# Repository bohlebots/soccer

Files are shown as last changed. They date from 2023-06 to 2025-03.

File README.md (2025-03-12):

# Bohlebots
<h2>collection of all published and open source software and hardware from the Bohlebots.</h2>
We are a team of students at the Gymnasium Haan in Germany. We call ourselves Bohlebots
due to the support of the Bohle company at our home town Haan.

We decided to put all our robotic stuff opensource. This includes arduino files and libraries,
eagle pcb files () and eagle libraries (lbr) for all our baords.
This page is under construction and it suffers from the inactivity of the author.
BUT:

We are also taking part at the development of the https://github.com/CoRoSoN-Kit/CoRoSoN-Kit.
The aktual bohlbots CoRoSoN Kit is lokated under https://github.com/ItzJannis/CoRoSoN-Package_Draft

Here is a photo of the prototypes of a mainboard and an IR-seeker-ring:
grafik

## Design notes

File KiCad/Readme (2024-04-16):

These are the current KiCad project files of the season 2024.
These boards are used by the bohlebots 1vs1 teams and can be used as CoRoSoN Kit boards as well

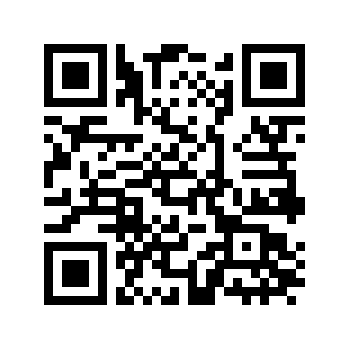
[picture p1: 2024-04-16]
KiCad/github.png

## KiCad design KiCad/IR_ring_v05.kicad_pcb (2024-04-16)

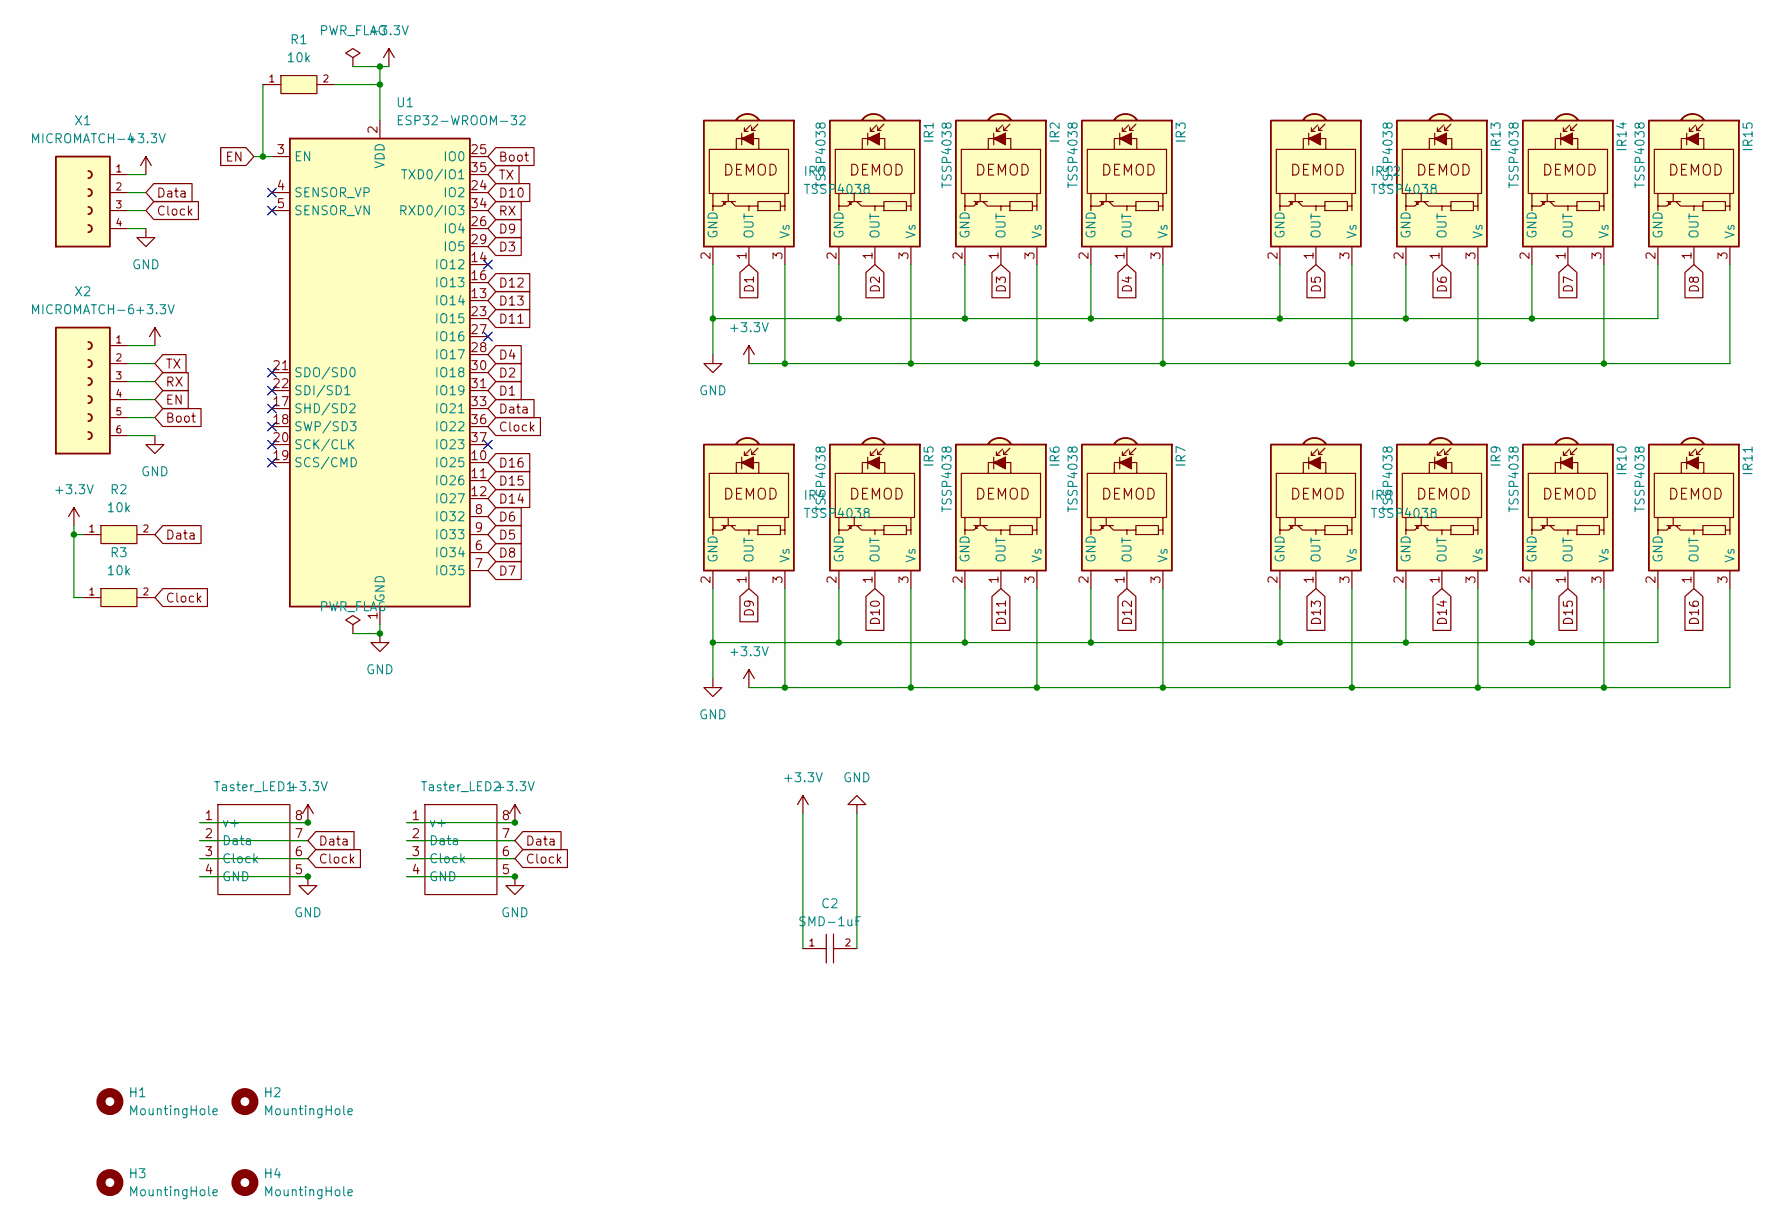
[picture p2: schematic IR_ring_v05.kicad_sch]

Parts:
C2: SMD-1uF; C0603; LCSC C1592
H1, H2, H3, H4: MountingHole; MountingHole_4.3mm_M4
IR0, IR1, IR2, IR3, IR4, IR5, IR6, IR7, IR8, IR9, IR10, IR11, IR12, IR13, IR14, IR15: TSSP4038; SENSOR-TH_TSSP40X_verschoben; LCSC Part # C143753
R1, R2, R3: 10k; R0603; LCSC C465463
Taster_LED1, Taster_LED2: TASTER_LED
U1: ESP32-WROOM-32; ESP32-WROOM-32-small; LCSC Part # C82899
X1: MICROMATCH-4
X2: MICROMATCH-6

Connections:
+3.3V: C2.1, IR0.3 (Vs), IR1.3 (Vs), IR2.3 (Vs), IR3.3 (Vs), IR4.3 (Vs), IR5.3 (Vs), IR6.3 (Vs), IR7.3 (Vs), IR8.3 (Vs), IR9.3 (Vs), IR10.3 (Vs), IR11.3 (Vs), IR12.3 (Vs), IR13.3 (Vs), IR14.3 (Vs), IR15.3 (Vs), R1.2, R2.1, R3.1, Taster_LED1.1 (v+), Taster_LED1.8, Taster_LED2.1 (v+), Taster_LED2.8, U1.2 (VDD), X1.1, X2.1
Boot: U1.25 (IO0), X2.5
Clock: R3.2, Taster_LED1.3 (Clock), Taster_LED1.6, Taster_LED2.3 (Clock), Taster_LED2.6, U1.36 (IO22), X1.3
D1: IR0.1 (OUT), U1.31 (IO19)
D2: IR1.1 (OUT), U1.30 (IO18)
D3: IR2.1 (OUT), U1.29 (IO5)
D4: IR3.1 (OUT), U1.28 (IO17)
D5: IR12.1 (OUT), U1.9 (IO33)
D6: IR13.1 (OUT), U1.8 (IO32)
D7: IR14.1 (OUT), U1.7 (IO35)
D8: IR15.1 (OUT), U1.6 (IO34)
D9: IR4.1 (OUT), U1.26 (IO4)
D10: IR5.1 (OUT), U1.24 (IO2)
D11: IR6.1 (OUT), U1.23 (IO15)
D12: IR7.1 (OUT), U1.16 (IO13)
D13: IR8.1 (OUT), U1.13 (IO14)
D14: IR9.1 (OUT), U1.12 (IO27)
D15: IR10.1 (OUT), U1.11 (IO26)
D16: IR11.1 (OUT), U1.10 (IO25)
Data: R2.2, Taster_LED1.2 (Data), Taster_LED1.7, Taster_LED2.2 (Data), Taster_LED2.7, U1.33 (IO21), X1.2
EN: R1.1, U1.3 (EN), X2.4
GND: C2.2, IR0.2 (GND), IR1.2 (GND), IR2.2 (GND), IR3.2 (GND), IR4.2 (GND), IR5.2 (GND), IR6.2 (GND), IR7.2 (GND), IR8.2 (GND), IR9.2 (GND), IR10.2 (GND), IR11.2 (GND), IR12.2 (GND), IR13.2 (GND), IR14.2 (GND), IR15.2 (GND), Taster_LED1.4 (GND), Taster_LED1.5, Taster_LED2.4 (GND), Taster_LED2.5, U1.1 (GND), U1.15 (GND), U1.38 (GND), U1.39 (GND), X1.4, X2.6
RX: U1.34 (RXD0/IO3), X2.3
TX: U1.35 (TXD0/IO1), X2.2

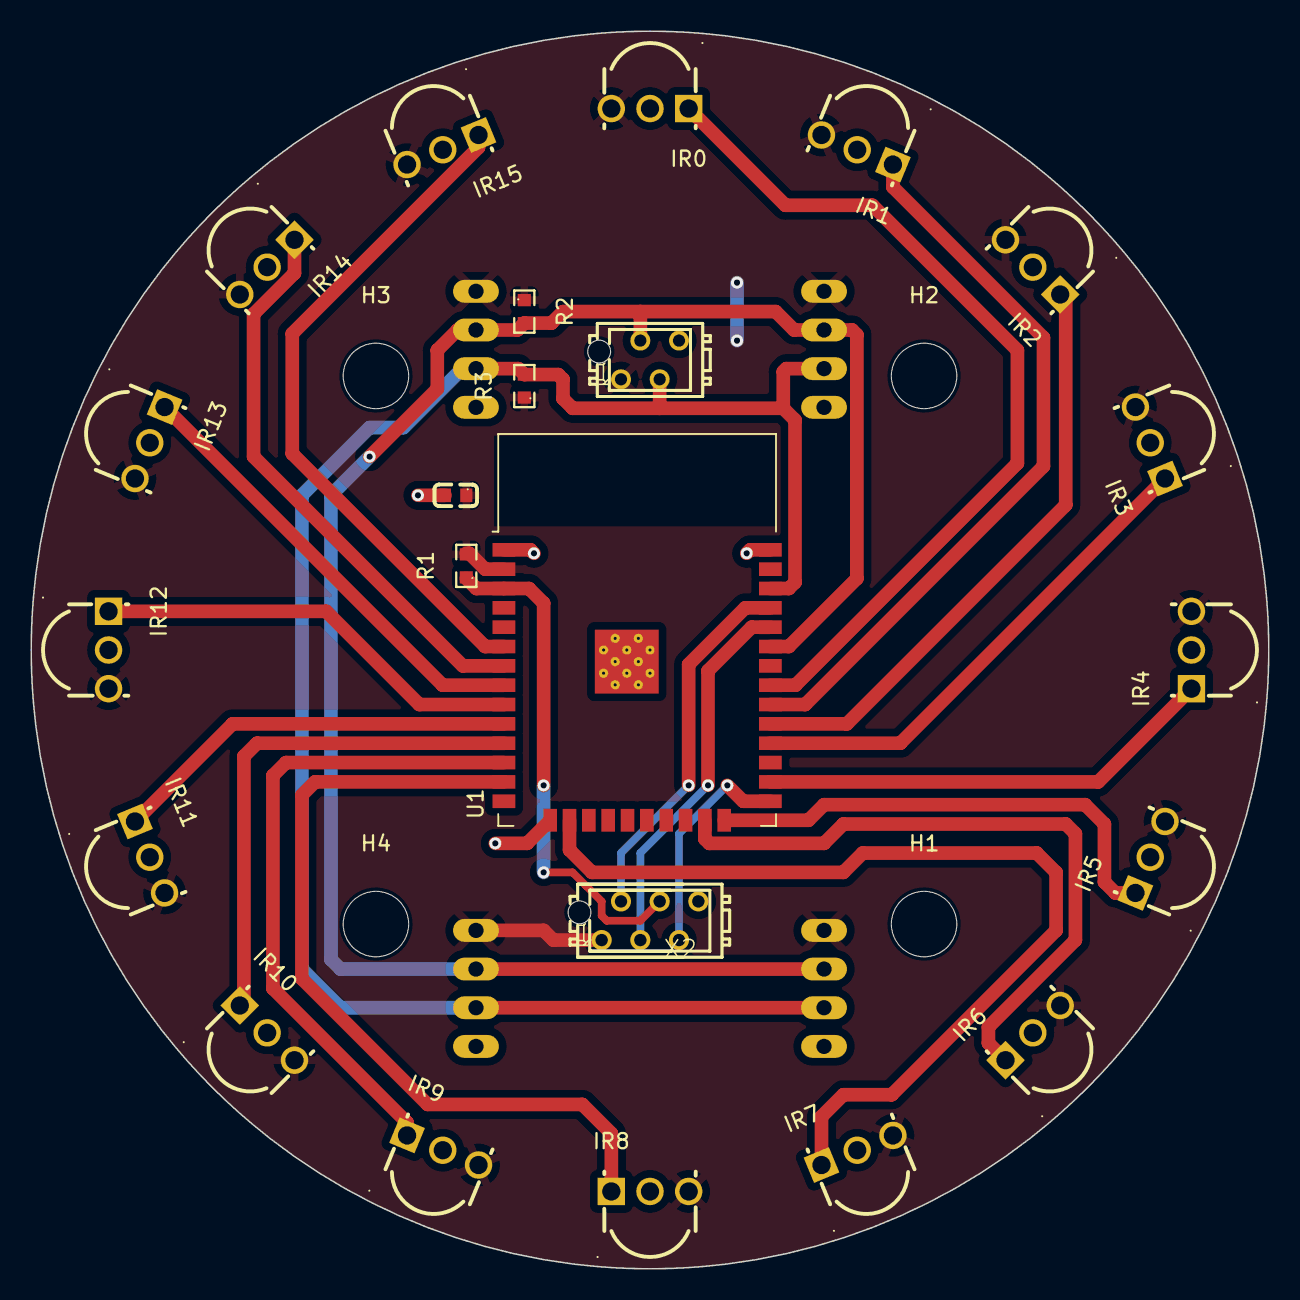
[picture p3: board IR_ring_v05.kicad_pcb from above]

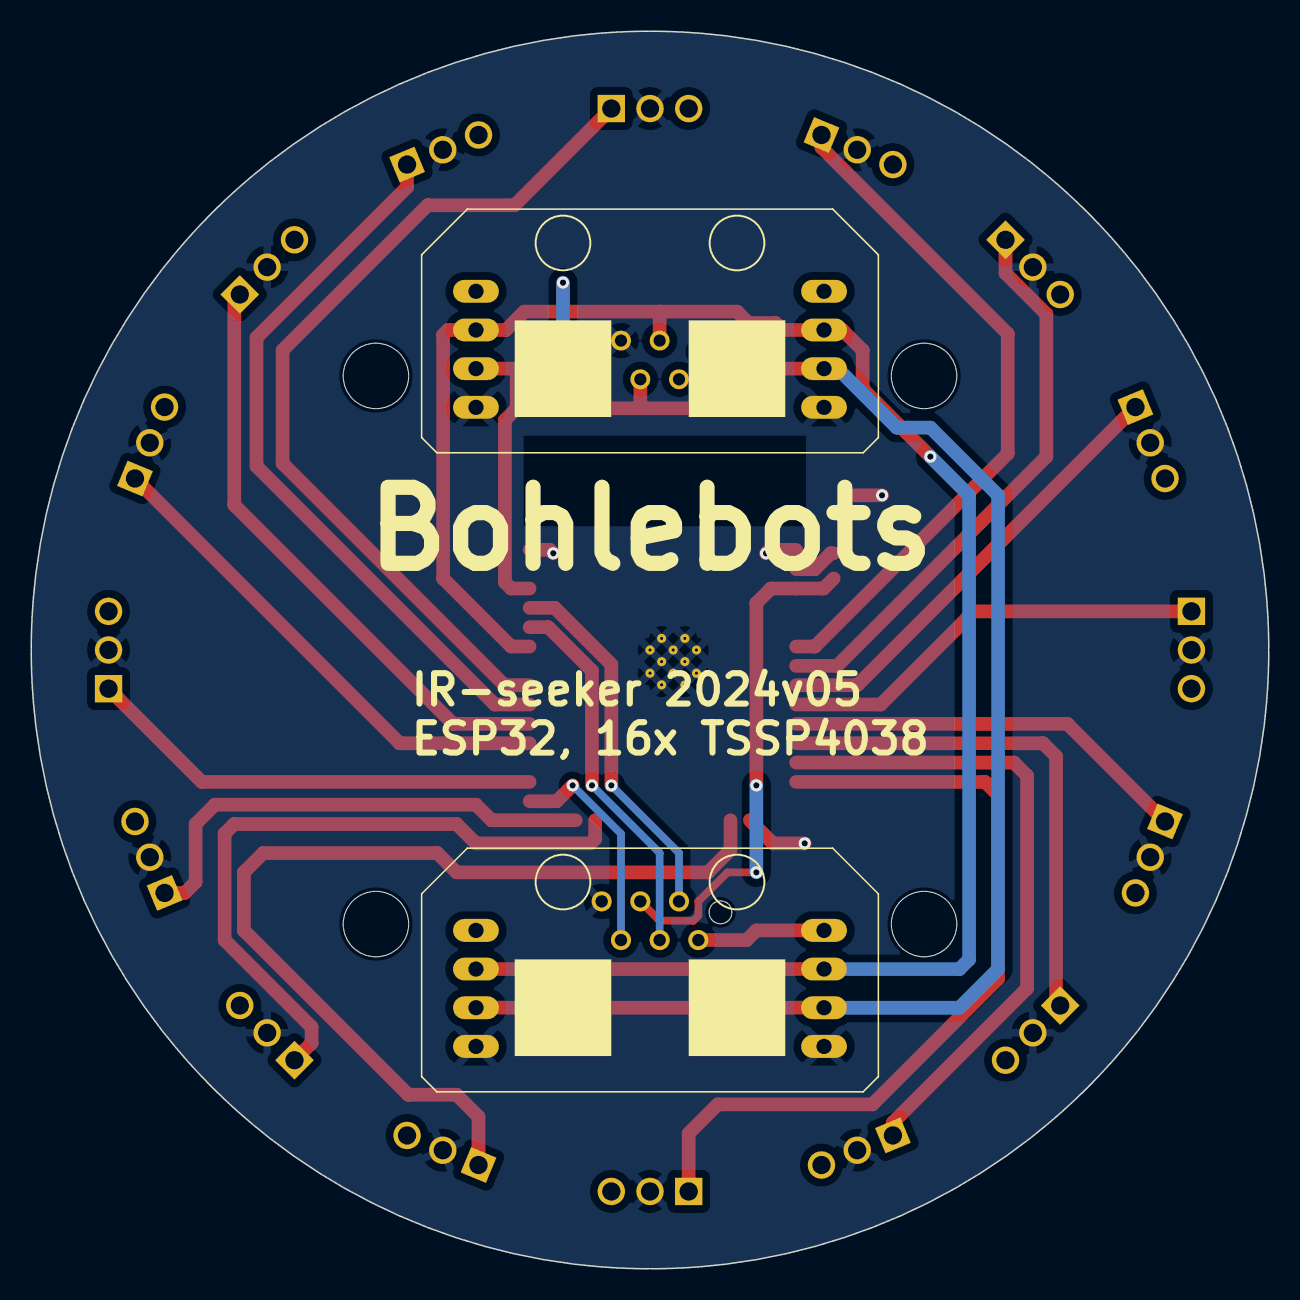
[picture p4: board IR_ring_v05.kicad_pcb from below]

Board: 2 copper layers, 81.3 x 81.3 mm, 29 parts (2 on the bottom side), 24 nets.

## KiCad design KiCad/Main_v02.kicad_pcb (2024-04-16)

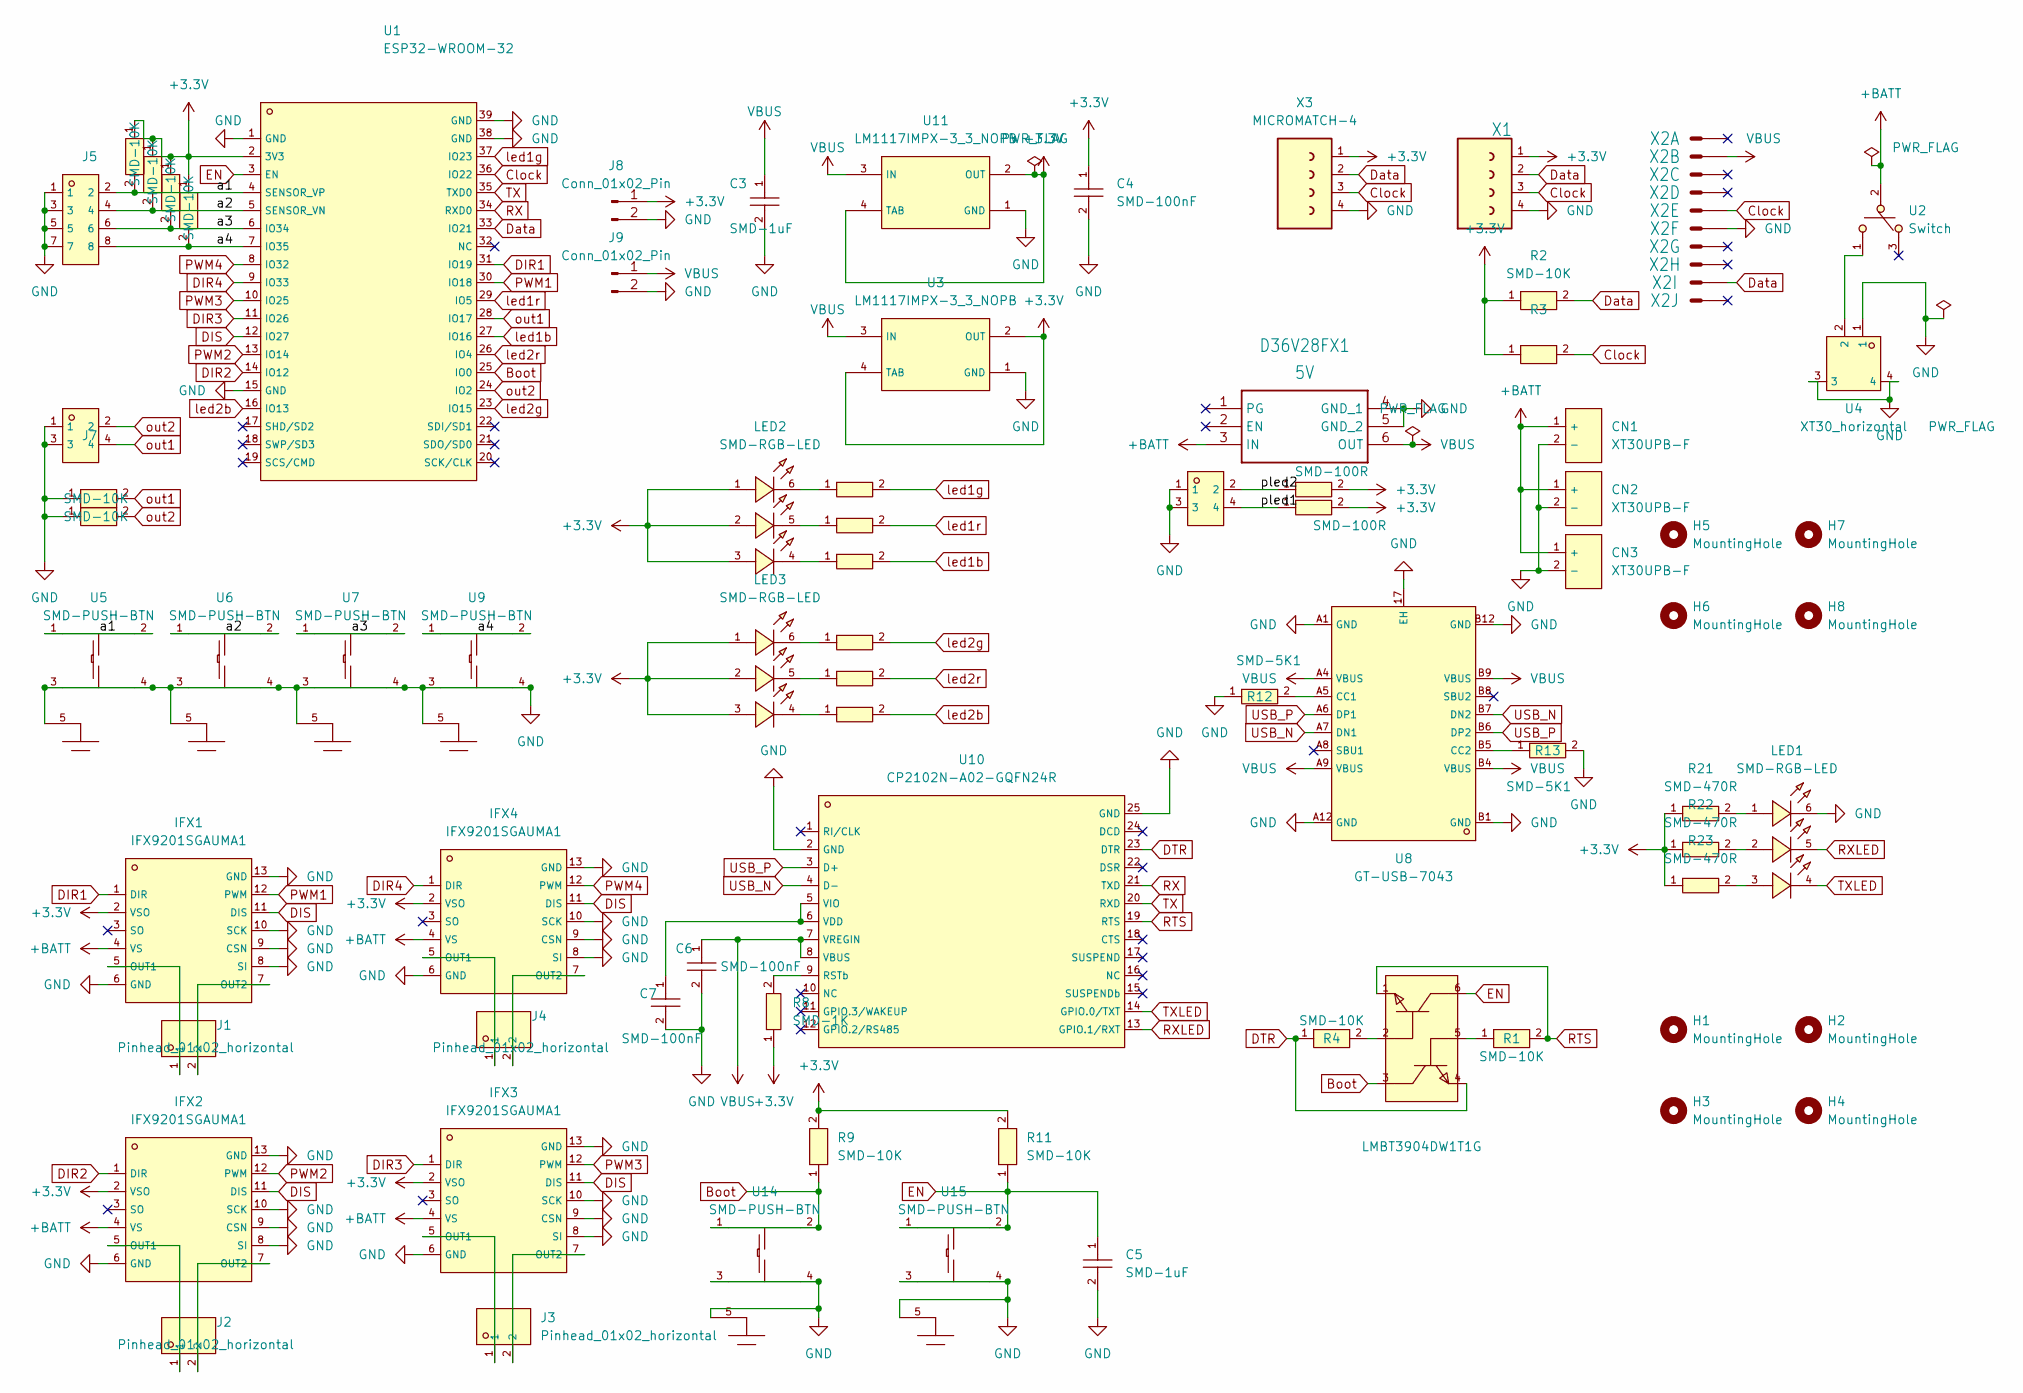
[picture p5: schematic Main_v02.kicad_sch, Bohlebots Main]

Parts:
C3, C5: SMD-1uF; C0603; LCSC C1592
C4, C6, C7: SMD-100nF; C0603; LCSC C30926
CN1, CN2, CN3: XT30UPB-F; CONN-TH_XT30UPB-F; LCSC C108769
D36V28FX1: 5V; D36V28FX
H1, H2, H3, H4, H5, H6, H7, H8: MountingHole; MountingHole_4.3mm_M4
IFX1, IFX2, IFX3, IFX4: IFX9201SGAUMA1; SO-12_L6.4-W7.5-P1.00-LS10.3-BL-EP; LCSC C112633
J1, J2, J3, J4: Pinhead_01x02_horizontal; HDR-TH_2P-P2.54-H-M-W10.4; LCSC C492410
J5: Conn_02x04_Row_Letter_First; HDR-TH_8P-P2.54-H-M-R2-C4-S2.54; LCSC C706885
J6, J7: Conn_02x02_Row_Letter_First; HDR-TH_4P-P2.54-H-M-R2-C2-S2.54-W12.3-N; LCSC C706883
J8, J9: Conn_01x02_Pin; PinHeader_1x02_P2.54mm_Vertical
LED1, LED2, LED3: SMD-RGB-LED; LED-SMD_6P-L5.0-W5.0-TL_TC5050RGBF08; LCSC C784540
R1, R2, R3, R4, R5, R6, R7, R9, R10, R11, R14, R15: SMD-10K; R0603; LCSC C465463
R8: SMD-1K; R0603; LCSC C22548
R12, R13: SMD-5K1; R0603; LCSC C103696
R16, R17, R20, R21, R22, R23, R24, R25, R26: SMD-470R; R0603; LCSC C23162
R18, R19: SMD-100R; R0603; LCSC C22775
U1: ESP32-WROOM-32; WIFIM-SMD_ESP32-WROOM-32-N4; LCSC C82899
U2: Switch; SW-TH_MT-0-103-A101-M200-RS; LCSC C1788498
U3, U11: LM1117IMPX-3_3_NOPB; SOT-223_L6.5-W3.5-P2.30-LS7.0-BR; LCSC C23984
U4: XT30_horizontal; CONN-TH_XT30PW-M; LCSC C431092
U5, U6, U7, U9, U14, U15: SMD-PUSH-BTN; SW-TH_5P-L6.0-W6.0-P4.50-LS6.5; LCSC C470256
U8: GT-USB-7043; USB-C-SMD_GT-USB-7043; LCSC C2762982
U10: CP2102N-A02-GQFN24R; QFN-24_L4.0-W4.0-P0.50-TL-EP2.6; LCSC C969151
U12: LMBT3904DW1T1G; SOT-363_L2.0-W1.3-P0.65-LS2.1-BR; LCSC C131781
X1: MICROMATCH-4
X2: MICROMATCH-10
X3: MICROMATCH-4

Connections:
+3.3V: C4.1, IFX1.2 (VSO), IFX2.2 (VSO), IFX3.2 (VSO), IFX4.2 (VSO), J8.1, LED2.1 (+), LED2.2 (+), LED2.3 (+), LED3.1 (+), LED3.2 (+), LED3.3 (+), R2.1, R3.1, R5.1, R6.1, R7.1, R8.1, R9.2, R10.1, R11.2, R18.2, R19.2, R21.1, R22.1, R23.1, U1.2 (3V3), U3.2 (OUT), U3.4 (TAB), U11.2 (OUT), U11.4 (TAB), X1.1, X3.1
+BATT: CN1.1 (+), CN2.1 (+), CN3.1 (+), D36V28FX1.3 (IN), IFX1.4 (VS), IFX2.4 (VS), IFX3.4 (VS), IFX4.4 (VS), U2.2
/a1: J5.2, R5.2, U1.4 (SENSOR_VP), U5.1, U5.2
/a2: J5.4, R6.2, U1.5 (SENSOR_VN), U6.1, U6.2
/a3: J5.6, R7.2, U1.6 (IO34), U7.1, U7.2
/a4: J5.8, R10.2, U1.7 (IO35), U9.1, U9.2
/pled1: J6.4, R19.1
/pled2: J6.2, R18.1
Boot: R9.1, U1.25 (IO0), U12.3 (C), U14.1, U14.2
Clock: R3.2, U1.36 (IO22), X1.3, X2.5 (S), X3.3
DIR1: IFX1.1 (DIR), U1.31 (IO19)
DIR2: IFX2.1 (DIR), U1.14 (IO12)
DIR3: IFX3.1 (DIR), U1.11 (IO26)
DIR4: IFX4.1 (DIR), U1.9 (IO33)
DIS: IFX1.11 (DIS), IFX2.11 (DIS), IFX3.11 (DIS), IFX4.11 (DIS), U1.12 (IO27)
DTR: R4.1, U10.23 (DTR), U12.4 (E)
Data: R2.2, U1.33 (IO21), X1.2, X2.9 (S), X3.2
EN: C5.1, R11.1, U1.3 (EN), U12.6 (C), U15.1, U15.2
GND: C3.2, C4.2, C5.2, C6.2, C7.2, CN1.2 (-), CN2.2 (-), CN3.2 (-), D36V28FX1.4 (GND_1), D36V28FX1.5 (GND_2), IFX1.6 (GND), IFX1.8 (SI), IFX1.9 (CSN), IFX1.10 (SCK), IFX1.13 (GND), IFX2.6 (GND), IFX2.8 (SI), IFX2.9 (CSN), IFX2.10 (SCK), IFX2.13 (GND), IFX3.6 (GND), IFX3.8 (SI), IFX3.9 (CSN), IFX3.10 (SCK), IFX3.13 (GND), IFX4.6 (GND), IFX4.8 (SI), IFX4.9 (CSN), IFX4.10 (SCK), IFX4.13 (GND), J5.1, J5.3, J5.5, J5.7, J6.1, J6.3, J7.1, J7.3, J8.2, J9.2, LED1.6 (-), R12.1, R13.2, R14.1, R15.1, U1.1 (GND), U1.15 (GND), U1.38 (GND), U1.39 (GND), U3.1 (GND), U4.1, U4.3, U4.4, U5.3, U5.4, U5.5, U6.3, U6.4, U6.5, U7.3, U7.4, U7.5, U8.17 (EH), U8.A1 (GND), U8.A12 (GND), U8.B1 (GND), U8.B12 (GND), U9.3, U9.4, U9.5, U10.2 (GND), U10.25 (GND), U11.1 (GND), U14.3, U14.4, U14.5, U15.3, U15.4, U15.5, X1.4, X2.6 (S), X3.4
unnamed: IFX1.5 (OUT1), J1.1
unnamed: IFX1.7 (OUT2), J1.2
unnamed: IFX2.5 (OUT1), J2.1
unnamed: IFX2.7 (OUT2), J2.2
unnamed: IFX3.5 (OUT1), J3.1
unnamed: IFX3.7 (OUT2), J3.2
unnamed: IFX4.5 (OUT1), J4.1
unnamed: IFX4.7 (OUT2), J4.2
unnamed: LED1.1 (+), R21.2
unnamed: LED1.2 (+), R22.2
unnamed: LED1.3 (+), R23.2
unnamed: LED2.4 (-), R20.1
unnamed: LED2.5 (-), R17.1
unnamed: LED2.6 (-), R16.1
unnamed: LED3.4 (-), R26.1
unnamed: LED3.5 (-), R25.1
unnamed: LED3.6 (-), R24.1
unnamed: R1.1, U12.5 (B)
unnamed: R4.2, U12.2 (B)
unnamed: U2.1, U4.2
unnamed: R12.2, U8.A5 (CC1)
unnamed: R13.1, U8.B5 (CC2)
unnamed: R8.2, U10.9 (RSTb)
unnamed: C7.1, U10.5 (VIO), U10.6 (VDD)
PWM1: IFX1.12 (PWM), U1.30 (IO18)
PWM2: IFX2.12 (PWM), U1.13 (IO14)
PWM3: IFX3.12 (PWM), U1.10 (IO25)
PWM4: IFX4.12 (PWM), U1.8 (IO32)
RTS: R1.2, U10.19 (RTS), U12.1 (E)
RX: U1.34 (RXD0), U10.21 (TXD)
RXLED: LED1.5 (-), U10.13 (GPIO.1/RXT)
TX: U1.35 (TXD0), U10.20 (RXD)
TXLED: LED1.4 (-), U10.14 (GPIO.0/TXT)
USB_N: U8.A7 (DN1), U8.B7 (DN2), U10.4 (D-)
USB_P: U8.A6 (DP1), U8.B6 (DP2), U10.3 (D+)
VBUS: C3.1, C6.1, D36V28FX1.6 (OUT), J9.1, U3.3 (IN), U8.A4 (VBUS), U8.A9 (VBUS), U8.B4 (VBUS), U8.B9 (VBUS), U10.7 (VREGIN), U10.8 (VBUS), U11.3 (IN), X2.2 (S)
led1b: R20.2, U1.27 (IO16)
led1g: R16.2, U1.37 (IO23)
led1r: R17.2, U1.29 (IO5)
led2b: R26.2, U1.16 (IO13)
led2g: R24.2, U1.23 (IO15)
led2r: R25.2, U1.26 (IO4)
out1: J7.4, R14.2, U1.28 (IO17)
out2: J7.2, R15.2, U1.24 (IO2)

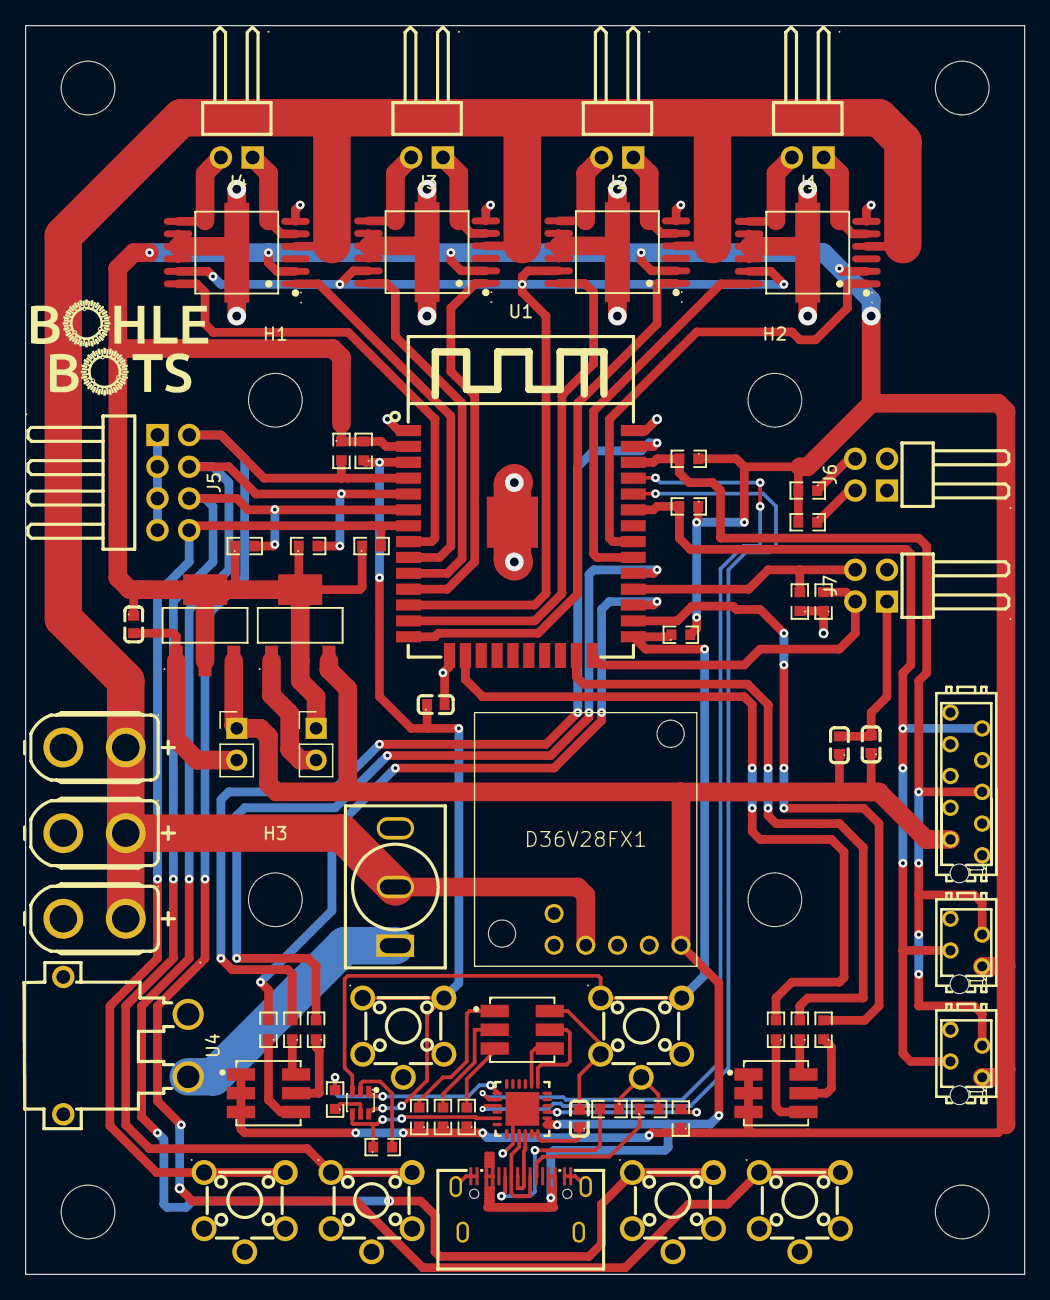
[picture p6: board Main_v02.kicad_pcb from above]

Board: 2 copper layers, 80.0 x 100.0 mm, 76 parts (0 on the bottom side), 63 nets.

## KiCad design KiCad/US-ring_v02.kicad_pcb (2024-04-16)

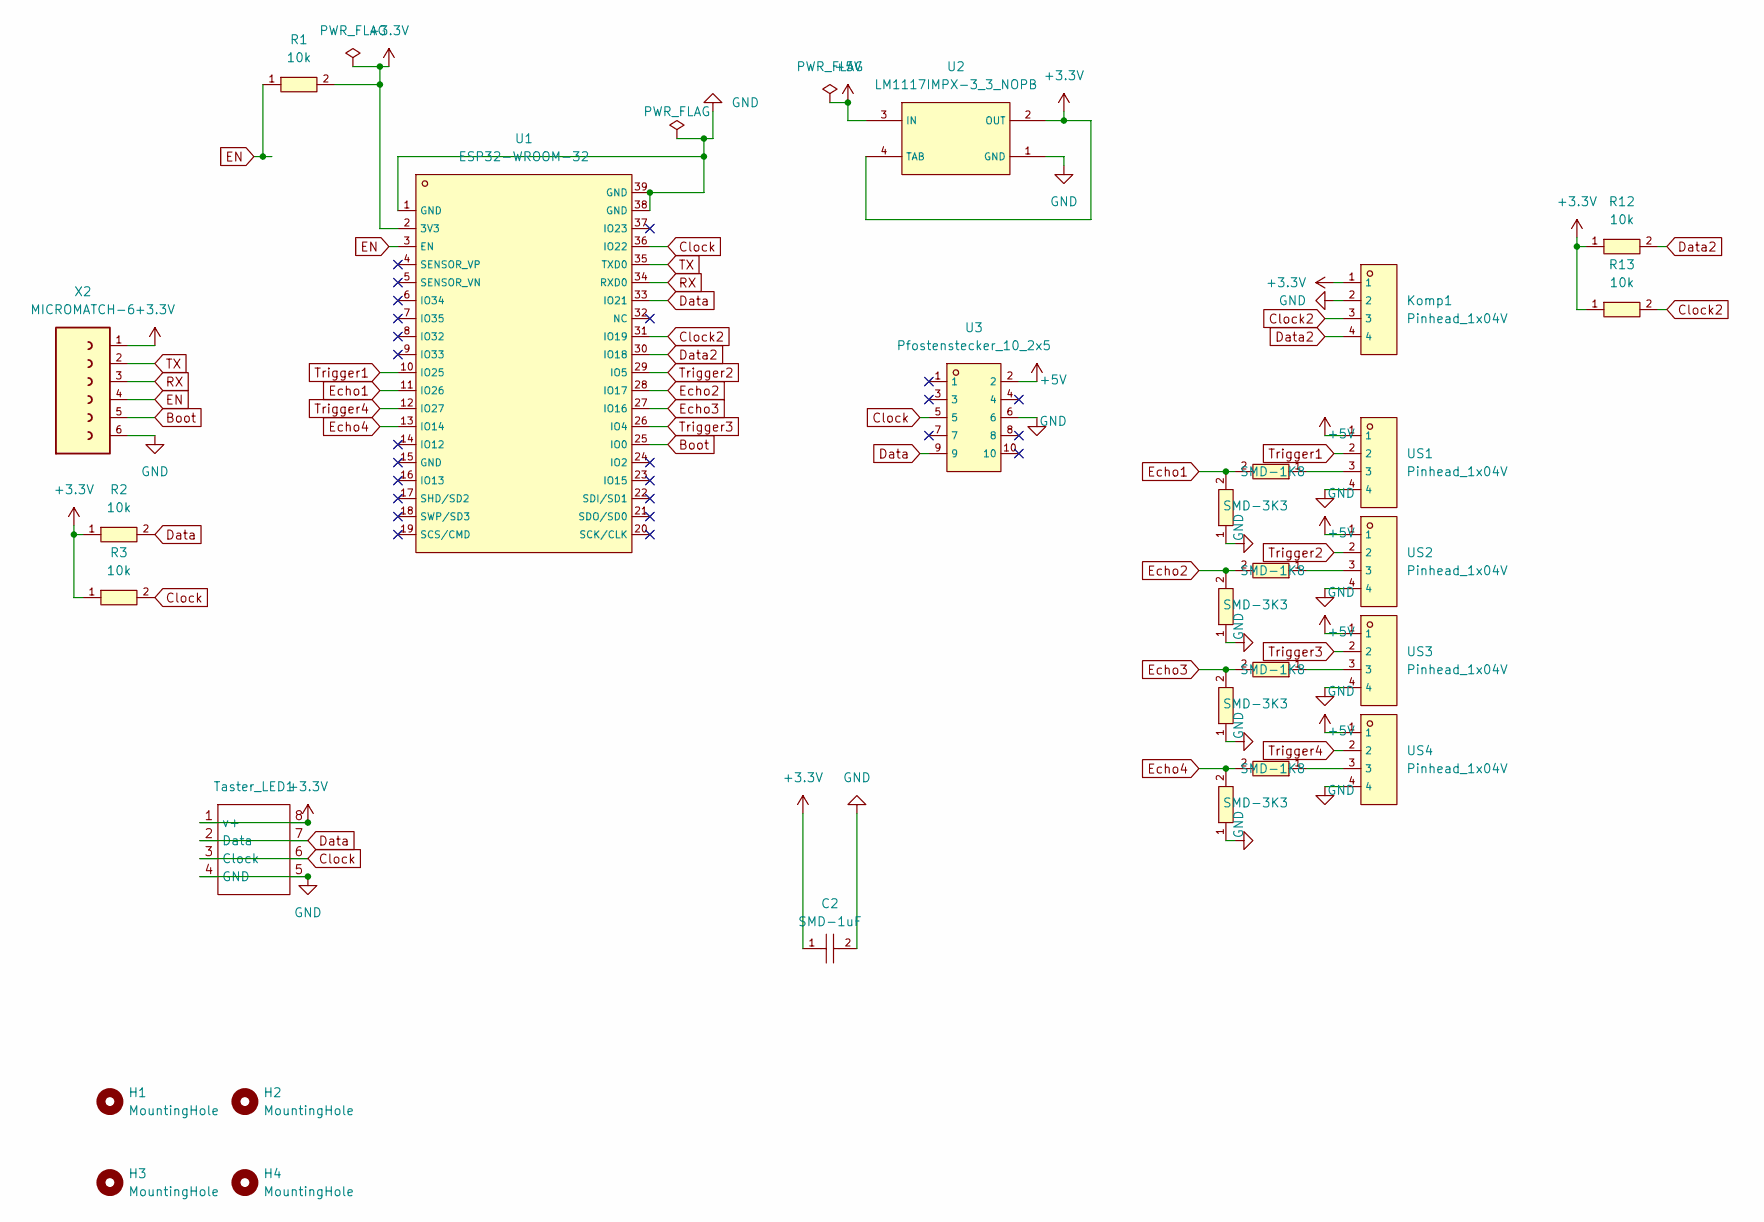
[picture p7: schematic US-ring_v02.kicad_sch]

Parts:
C2: SMD-1uF; C0603; LCSC C1592
H1, H2, H3, H4: MountingHole; MountingHole_4.3mm_M4
Komp1: Pinhead_1x04V; HDR-TH_4P-P2.54-V-M-1; LCSC C920779
R1, R2, R3, R12, R13: 10k; R0603; LCSC C25804
R4, R7, R8, R10: SMD-3K3; R0603; LCSC C22978
R5, R6, R9, R11: SMD-1K8; R0603; LCSC C4177
Taster_LED1: TASTER_LED
U1: ESP32-WROOM-32; WIFIM-SMD_ESP32-WROOM-32-N4; LCSC Part # C82899
U2: LM1117IMPX-3_3_NOPB; SOT-223_L6.5-W3.5-P2.30-LS7.0-BR; LCSC C23984
U3: Pfostenstecker_10_2x5; HDR-TH_10P-P2.54-V-F-R2-C5-S2.54-5; LCSC C5372865
US1, US2, US3, US4: Pinhead_1x04V; HDR-TH_4P-P2.54-V-M-1; LCSC C920779
X2: MICROMATCH-6

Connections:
+3.3V: C2.1, Komp1.1, R1.2, R2.1, R3.1, R12.1, R13.1, Taster_LED1.1 (v+), Taster_LED1.8, U1.2 (3V3), U2.2 (OUT), U2.4 (TAB), X2.1
+5V: U2.3 (IN), U3.2, US1.1, US2.1, US3.1, US4.1
Boot: U1.25 (IO0), X2.5
Clock: R3.2, Taster_LED1.3 (Clock), Taster_LED1.6, U1.36 (IO22), U3.5
Clock2: Komp1.3, R13.2, U1.31 (IO19)
Data: R2.2, Taster_LED1.2 (Data), Taster_LED1.7, U1.33 (IO21), U3.9
Data2: Komp1.4, R12.2, U1.30 (IO18)
EN: R1.1, U1.3 (EN), X2.4
Echo1: R10.2, R11.2, U1.11 (IO26)
Echo2: R6.2, R7.2, U1.28 (IO17)
Echo3: R4.2, R5.2, U1.27 (IO16)
Echo4: R8.2, R9.2, U1.13 (IO14)
GND: C2.2, Komp1.2, R4.1, R7.1, R8.1, R10.1, Taster_LED1.4 (GND), Taster_LED1.5, U1.1 (GND), U1.38 (GND), U1.39 (GND), U2.1 (GND), U3.6, US1.4, US2.4, US3.4, US4.4, X2.6
unnamed: R5.1, US3.3
unnamed: R6.1, US2.3
unnamed: R9.1, US4.3
unnamed: R11.1, US1.3
RX: U1.34 (RXD0), X2.3
TX: U1.35 (TXD0), X2.2
Trigger1: U1.10 (IO25), US1.2
Trigger2: U1.29 (IO5), US2.2
Trigger3: U1.26 (IO4), US3.2
Trigger4: U1.12 (IO27), US4.2

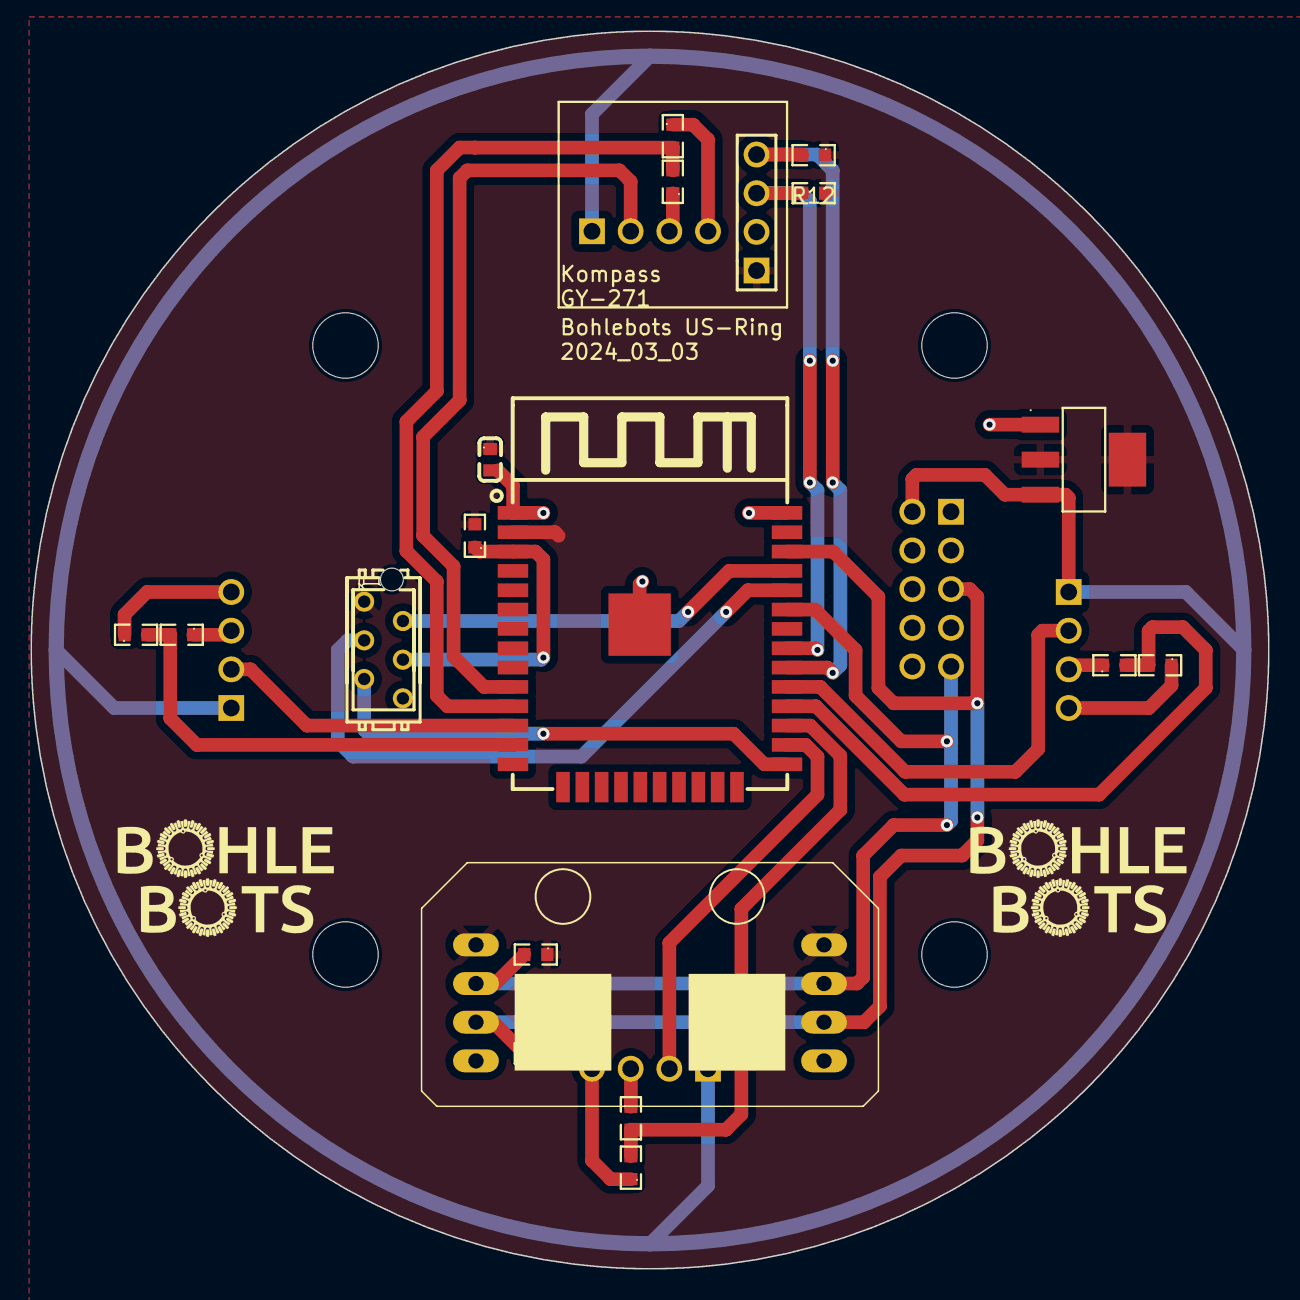
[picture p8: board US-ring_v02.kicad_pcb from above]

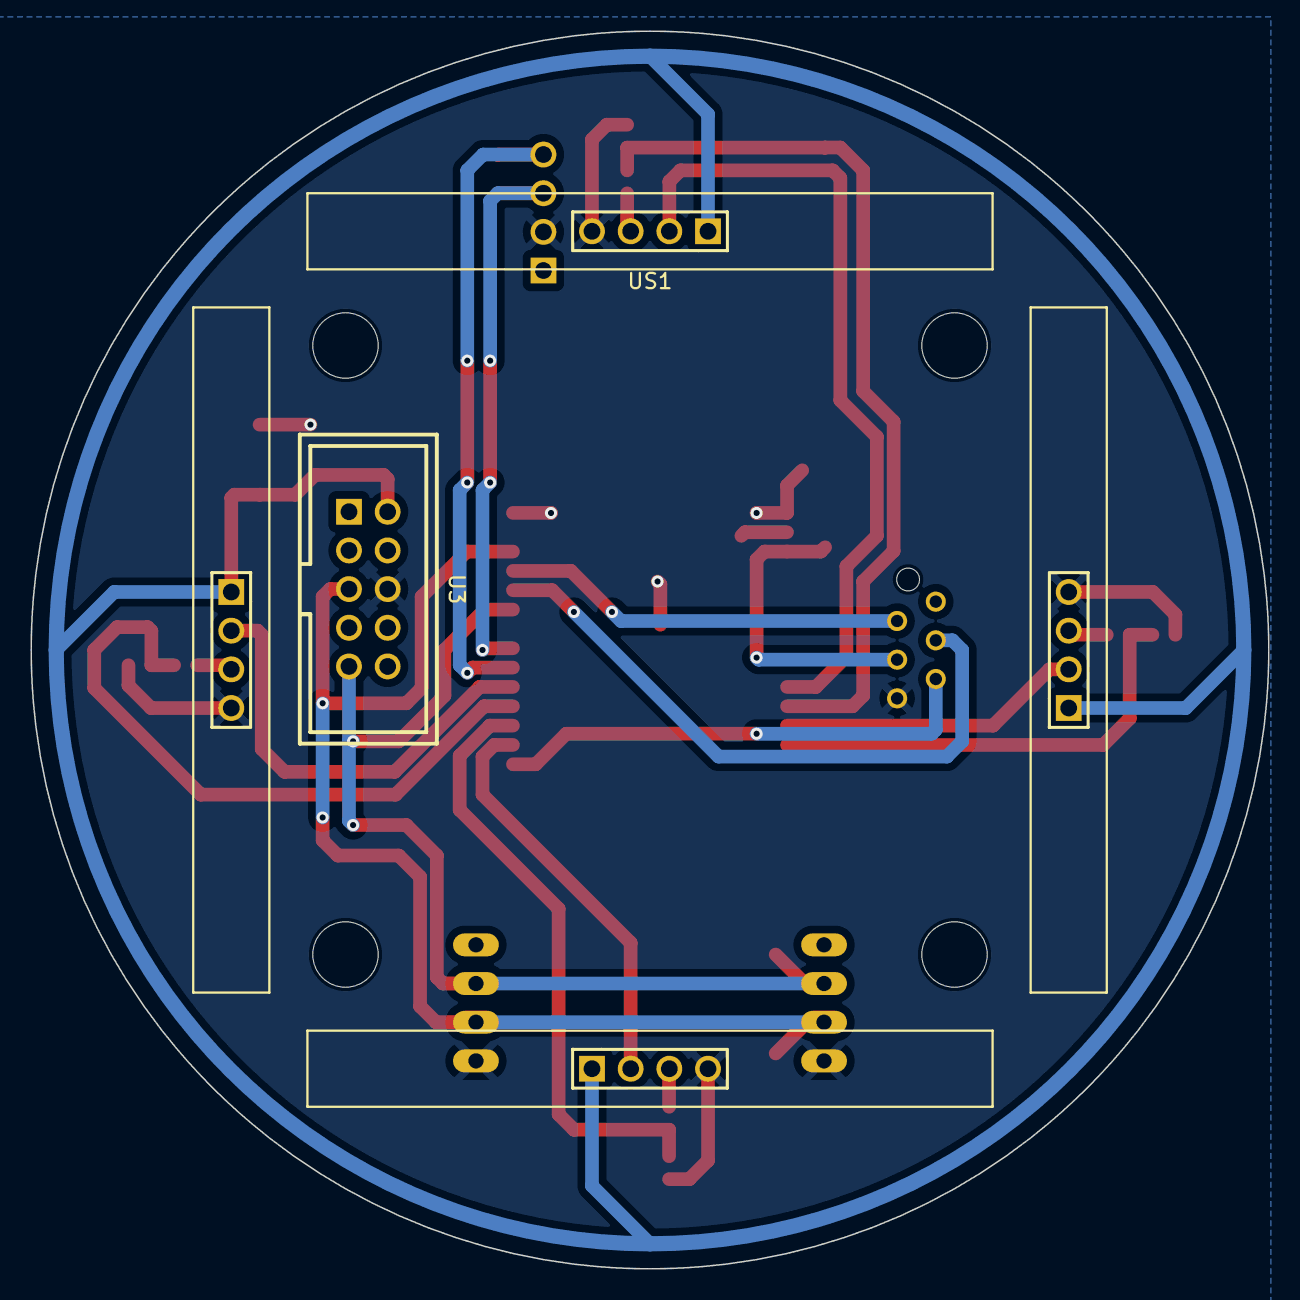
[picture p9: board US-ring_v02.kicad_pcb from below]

Board: 2 copper layers, 81.3 x 81.3 mm, 28 parts (5 on the bottom side), 23 nets.

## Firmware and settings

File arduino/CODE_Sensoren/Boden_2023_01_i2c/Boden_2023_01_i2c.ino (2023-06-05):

/*
   Bodensensor Canbus Platine 2022_01_10
		Serielle ausgabe in Line 215
*/

#include <elapsedMillis.h>
#include <Wire.h>
#define I2C_DEV_ADDR 0x30
#define TOT 2 // hier wird die Totzeit gesetzt. Je ein TOT entspricht 20ms. eine TOT von 5 ist 100ms

#include "Zuordnung.h"
elapsedMillis zeit;

int schwellwert = 250;  // setzen und immer wieder prüfen !!!


int sensor[] = { 26, 33, 32, 25}; // 4 Ananlogeingänge für 4 Multiplexer
int zonen[] = { 0, 0, 0, 0, 0, 0, 0, 0, 0};
byte zuordnungzone = 0b00000000;

int bodenled = 2;

int add0 = 13; // 8 port Multiplexer Adressleitungen
int add1 = 27;
int add2 = 14;

boolean sieht_weiss = false;
boolean weiss_abweichung = false;
boolean weiss_klar = false;
int weiss_winkel;
int weiss_winkel_save;
byte weiss_byte;
byte weiss_paket;
int weiss_totzeit;
char ausgabe[8];

void onRequest(){
  Wire.print(weiss_paket);
}

void onReceive(int len){
  Serial.printf("onReceive[%d]: ", len);
  while(Wire.available()){
    Serial.write(Wire.read());
  }
  Serial.println();
}


// nur für debug-zwecke......
void printBits(byte myByte)
{
  for (byte mask = 0x80; mask; mask >>= 1)
  {
    if (mask  & myByte) Serial.print('1');
    else               Serial.print('0');
  }
}
// Ende nur für debug-zwecke......



void setup()
{
  pinMode(bodenled, OUTPUT);
  pinMode(add0, OUTPUT);
  pinMode(add1, OUTPUT);
  pinMode(add2, OUTPUT);

  Serial.begin(115200);
  digitalWrite(bodenled, LOW);

  setze_zuordnung();
  
  Wire.setPins(4, 5);
  Wire.onReceive(onReceive);
  Wire.onRequest(onRequest);
  Wire.begin((uint8_t)I2C_DEV_ADDR);
  //#if CONFIG_IDF_TARGET_ESP32 char message[64]; snprintf(message, 64, "%u Packets.", i++); Wire.slaveWrite((uint8_t *)message, strlen(message));
}
void setzeMultiplexer(int adresse)
{
  if ((adresse & 1) == 1) {
    digitalWrite(add0, HIGH); // die Adressports werden digital hochgezählt
  } else {
    digitalWrite(add0, LOW);
  }
  if ((adresse & 2) == 2) {
    digitalWrite(add1, HIGH);
  } else {
    digitalWrite(add1, LOW);
  }
  if ((adresse & 4) == 4) {
    digitalWrite(add2, HIGH);
  } else {
    digitalWrite(add2, LOW);
  }
  delayMicroseconds(60); // damit der multiplexer umschalten kann
}

void sensorread() // liest alle 64 Sensorwerte aus und speicher sie im Puffer ab.
{
  for (int z = 0; z < 8; z++)  zonen[z] = 0; // Alle Zonen auf "keine Linie" setzen

  for (int lauf=0; lauf<8; lauf++)
  {
    setzeMultiplexer(lauf);
    /*for (int innen=0; innen<4; innen++)
    {
      Serial.print(analogRead(sensor[innen]));Serial.print(", ");
    }
    Serial.println();*/
  }
  /*Serial.println();
  setzeMultiplexer(6);
  if (analogRead(sensor[3]) > schwellwert) Serial.println("6");
  //Serial.println(analogRead(sensor[0]));
  */
  setzeMultiplexer(2);  // r3
    if (analogRead(sensor[0]) > schwellwert) zonen[1] = zonen[1] + 1;
    if (analogRead(sensor[1]) > schwellwert) zonen[3] = zonen[3] + 1;
    if (analogRead(sensor[2]) > schwellwert) zonen[5] = zonen[5] + 1;
    if (analogRead(sensor[3]) > schwellwert) zonen[7] = zonen[7] + 1;
    
  setzeMultiplexer(4);  //r2
    if (analogRead(sensor[0]) > schwellwert) {zonen[0] = zonen[0] + 1;zonen[1] = zonen[1] + 1;}
    if (analogRead(sensor[1]) > schwellwert) {zonen[2] = zonen[2] + 1;zonen[3] = zonen[3] + 1;}
    if (analogRead(sensor[2]) > schwellwert) {zonen[4] = zonen[4] + 1;zonen[5] = zonen[5] + 1;}
    if (analogRead(sensor[3]) > schwellwert) {zonen[6] = zonen[6] + 1;zonen[7] = zonen[7] + 1;}
    
  setzeMultiplexer(0);  //r1
    if (analogRead(sensor[0]) > schwellwert) zonen[0] = zonen[0] + 1;
    if (analogRead(sensor[1]) > schwellwert) zonen[2] = zonen[2] + 1;
    if (analogRead(sensor[2]) > schwellwert) zonen[4] = zonen[4] + 1;
    if (analogRead(sensor[3]) > schwellwert) zonen[6] = zonen[6] + 1;
  
  setzeMultiplexer(6);  //mitte
    if (analogRead(sensor[0]) > schwellwert) zonen[0] = zonen[0] + 1;
    if (analogRead(sensor[1]) > schwellwert) zonen[2] = zonen[2] + 1;
    if (analogRead(sensor[2]) > schwellwert) zonen[4] = zonen[4] + 1;
    if (analogRead(sensor[3]) > schwellwert) zonen[6] = zonen[6] + 1;
    
  setzeMultiplexer(5);  //l1
    if (analogRead(sensor[0]) > schwellwert) zonen[0] = zonen[0] + 1;
    if (analogRead(sensor[1]) > schwellwert) zonen[2] = zonen[2] + 1;
    if (analogRead(sensor[2]) > schwellwert) zonen[4] = zonen[4] + 1;
    if (analogRead(sensor[3]) > schwellwert) zonen[6] = zonen[6] + 1;
  
  setzeMultiplexer(7);  //l2
    if (analogRead(sensor[0]) > schwellwert) {zonen[0] = zonen[0] + 1;zonen[7] = zonen[7] + 1;}
    if (analogRead(sensor[1]) > schwellwert) {zonen[2] = zonen[2] + 1;zonen[1] = zonen[1] + 1;}
    if (analogRead(sensor[2]) > schwellwert) {zonen[4] = zonen[4] + 1;zonen[3] = zonen[3] + 1;}
    if (analogRead(sensor[3]) > schwellwert) {zonen[6] = zonen[6] + 1;zonen[5] = zonen[5] + 1;}
    
  setzeMultiplexer(3);  //l3
    if (analogRead(sensor[0]) > schwellwert) zonen[7] = zonen[7] + 1;
    if (analogRead(sensor[1]) > schwellwert) zonen[1] = zonen[1] + 1;
    if (analogRead(sensor[2]) > schwellwert) zonen[3] = zonen[3] + 1;
    if (analogRead(sensor[3]) > schwellwert) zonen[5] = zonen[5] + 1;
  
  setzeMultiplexer(1);  //l4
    if (analogRead(sensor[0]) > schwellwert) zonen[7] = zonen[7] + 1;
    if (analogRead(sensor[1]) > schwellwert) zonen[1] = zonen[1] + 1;
    if (analogRead(sensor[2]) > schwellwert) zonen[3] = zonen[3] + 1;
    if (analogRead(sensor[3]) > schwellwert) zonen[5] = zonen[5] + 1;
 
  
} // end of sensorread()

void zone()
{
  zuordnungzone = 0b00000000;
  if (zonen[0] > 0) {
    zuordnungzone = zuordnungzone + 0b00000001;
  }
  if (zonen[1] > 0) {
    zuordnungzone = zuordnungzone + 0b00000010;
  }
  if (zonen[2] > 0) {
    zuordnungzone = zuordnungzone + 0b00000100;
  }
  if (zonen[3] > 0) {
    zuordnungzone = zuordnungzone + 0b00001000;
  }
  if (zonen[4] > 0) {
    zuordnungzone = zuordnungzone + 0b00010000;
  }
  if (zonen[5] > 0) {
    zuordnungzone = zuordnungzone + 0b00100000;
  }
  if (zonen[6] > 0) {
    zuordnungzone = zuordnungzone + 0b01000000;
  }
  if (zonen[7] > 0) {
    zuordnungzone = zuordnungzone + 0b10000000;
  }
}

void linie_erkennen()
{
  if (zuordnungzone > 0)   // weiße Linie wird irgendwo erkannt
  {
    weiss_totzeit = TOT;
    weiss_winkel   = zuordnung[zuordnungzone];
   
    // zuerst prüfen, ob die Linie ganz neu ist...
    if (sieht_weiss == false) weiss_winkel_save = weiss_winkel;              // save Wert ist neuwert !!!

    sieht_weiss = true;
    //Serial.println(weiss_winkel);
    // prüfen, ob die Werte etwas taugen
    if (weiss_winkel_save > 8)    // Sie taugen nichts. Mist!
    {
      weiss_winkel_save = 0;
      weiss_klar = false;
    }

    else      // die Linie wurde erkannt, die Savelinie ist klar definiert...
    {
      weiss_klar = true;
      // Abweichung 90 Grad oder weniger, inkl. Sprung von -7 bis 7   UND weiss_winkel klar definiert (also nicht 100 oder 200)
      if (((abs(weiss_winkel_save - weiss_winkel) < 5) | (abs(weiss_winkel_save - weiss_winkel) > 11)) & (weiss_winkel < 9)) // Abweichung 90 Grad oder weniger    // muss noch oder Sprung -7->8 und umgekehrt
      {
        weiss_winkel_save = weiss_winkel;
        weiss_abweichung = false;
      }
      else weiss_abweichung = true;
    }
  }

  else
  {
    if (weiss_totzeit > 0) weiss_totzeit--;
    else sieht_weiss = false;
  }


}

void pakete_erstellen()
{
  /*
     Bit 7    = 0
     Bit 6    Linie erkannt? -> Das Bit, welches zur Handlung zwingt... 1 für erkannt, 0 für nix
     Bit 5    Abweichung (aktuelle Linie == erste Linie ?) 0 für gleich, 1 für anders
     Bit 4    Klares Ergebnis (sollte immer so sein, aber wenn nicht -> Problem. 1 für gut, 0 für Problem
     Bit 0-3  16 unterschiedliche Richtungen -> Umwandeln auf -7 bis 8
  */
  weiss_byte = 0;
  if (sieht_weiss == true)      weiss_byte = weiss_byte + 64;
  if (weiss_abweichung == true) weiss_byte = weiss_byte + 32;
  if (weiss_klar == true)       weiss_byte = weiss_byte + 16;
  weiss_byte  = weiss_byte + (weiss_winkel_save + 7);
  // für CanBus
  weiss_paket = weiss_byte;
}


void loop()
{
  zeit = 0;

  digitalWrite(bodenled, HIGH);
  delayMicroseconds(100);             // eigentlich nur 100
  sensorread();                       //dauert weniger als 1ms - testen
  digitalWrite(bodenled, LOW);
  zone();
  linie_erkennen();
  pakete_erstellen();
  //nicht mehr Nötig, weil i2c per Interrupt gesteuert wird.
  //hoffentlich auf core1?
  //checkCanBus();
  //schreibe();
  //Serial.println(" Linie :" + String(weiss_abweichung));
  while (zeit < 2) delay(1); //checkCanBus();    // fülle auf 1 Sekunde auf - nur Diagnose !!!(momentan 2 milisekunden)
  
}


void schreibe()
{
  
  Serial.print(String(zonen[0])+",  ");
  Serial.print(String(zonen[1])+",  ");
  Serial.print(String(zonen[2])+",  ");
  Serial.print(String(zonen[3])+",  ");
  Serial.print(String(zonen[4])+",  ");
  Serial.print(String(zonen[5])+",  ");
  Serial.print(String(zonen[6])+",  ");
  Serial.print(String(zonen[7])      );
  Serial.println();
  
  
  
  /*
  Serial.print("Weiß    : ");   Serial.print("Zone : " );
  printBits(zuordnungzone);     Serial.println(" Linie :" + String(weiss_winkel));

  //Serial.println("Zeit   : "+String(zeit));
  Serial.println();
  Serial.println("weißpaket : " + String(weiss_paket));
  Serial.println();



  Serial.println(); Serial.println("Zeit   : " + String(zeit));
  Serial.println();
  */

}

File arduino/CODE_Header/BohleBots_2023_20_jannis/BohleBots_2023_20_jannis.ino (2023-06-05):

/*
 * Ver. 2023_05_08
 * rudimentäre Fahrlogik
 */ 

#include "BohleBots.h"
BohleBots bot;

#define LICHT_PIN 3

int tempo    = 40; // setzt das normale Fahrtempo
int maxTempo = 70; // setzt das maximal Fahrtempo

int altetorRichtung;
int alteRichtung;
int neueRichtung;
elapsedMillis richtungszeit;
// Achtung: kein delay im Hauptprogramm nutzen !!!
// statt dessen immer bot.warte(ms), mindestens 20ms
// dauert genau so lange, überprüft aber den i2cBus in der Zeit,
// damit Taster und andere Sensoren weiterhin abgefragt werden.

int modus = 0;

void setup() 
{
  bot = BohleBots(); 
  bot.linkesModul  = 1; //Zuordnung der TastsetLed Module
  bot.rechtesModul = 2; //auf die hardkodierten Adressen
                        // Auf den Modulen gilt: links=1, rechts=2  
  bot.setBotTyp(4);
  bot.setLichtPin(LICHT_PIN);
  bot.setBenutztPixy(true);
  bot.setBenutztKompass(false);
  bot.setBallSchwelle(500);
  bot.init();      
  
  Serial.println("kann losgehen...");
}


void changeModus()   //?
{
  if (bot.tastZeit < 1000) return;
  bot.tastZeit = 0;
  if (modus == 1) 
  {
    modus = 0;
    return;
  }
  if (modus == 0) 
  {
    modus = 1;
    bot.tastZeit = 500;
    return;
  }
}

void vorbereitung()
{
  bot.fahre(0, 0, 0);
  bot.setLed(bot.rechtesModul, 1, GRUEN);

  if (bot.taster(bot.rechtesModul, 2)) bot.kick(40);
  if (bot.taster(bot.linkesModul,  1)) bot.setKompassHeading();
  if (bot.taster(bot.linkesModul,  2)) bot.fahre(0, 0, 10);
  //if (bot.taster(bot.rechtesModul, 1)) //todo?

  if (!bot.siehtBall())             bot.setLed(bot.linkesModul, 2, ROT);
  else if (bot.ballRichtung() == 0) bot.setLed(bot.linkesModul, 2, GRUEN);
       else                         bot.setLed(bot.linkesModul, 2, MAGENTA);

  if (bot.hatBall()) bot.setLed(bot.rechtesModul, 2, BLAU); 
  else               bot.setLed(bot.rechtesModul, 2, AUS);

  //if      (abs(bot.kompass()) < 10)   bot.setLed(linkesModul, 1, GRUEN);      
  //else if (abs(bot.kompass()) < 30)   bot.setLed(linkesModul, 1, WEISS);
  //else if (abs(bot.kompass()) < 90)   bot.setLed(linkesModul, 1, MAGENTA);
  //else                                bot.setLed(linkesModul, 1, ROT);
  if (abs(bot.torRichtung()) < 60)  bot.setLed(bot.linkesModul, 1, BLAU);  
  if (abs(bot.torRichtung()) < 30)  bot.setLed(bot.linkesModul, 1, GELB);
  if (abs(bot.torRichtung()) < 10)  bot.setLed(bot.linkesModul, 1, GRUEN);
  if (!bot.siehtTor())              bot.setLed(bot.linkesModul, 1, ROT);
  //schreibe();
}

void strike()// Ball ist in der Ballschale
{
  bot.setLed(bot.rechtesModul, 2, BLAU); 
  if (bot.strikeZeit < 100) bot.fahre(0, maxTempo, bot.torRichtung() / 2);
  if (bot.strikeZeit < 5000) 
  {
    bot.fahre(0, 0, bot.torRichtung() / 2);
    bot.strikeZeit = 0;
    bot.kick(40);
  }
  else   //vielleicht raus???
  {
    bot.fahre(0, 0, 30);
  }
   
}

void suche() //wird ausgeführt, wenn der Ball an ist, aber nicht in der Ballschale ist
{  
    if (bot.ballRichtung() ==  0) neueRichtung =    0;
    if (bot.ballRichtung() ==  1) neueRichtung =   45;
    if (bot.ballRichtung() ==  2) neueRichtung =   90;
    if (bot.ballRichtung() ==  3) neueRichtung =   90;
    if (bot.ballRichtung() ==  4) neueRichtung =  135;
    if (bot.ballRichtung() ==  6) neueRichtung =  180;
    if (bot.ballRichtung() ==  5) neueRichtung =  135;
    if (bot.ballRichtung() ==  6) neueRichtung =  180;
    if (bot.ballRichtung() ==  7) neueRichtung = -135;
    if (bot.ballRichtung() ==  8) neueRichtung = -135;
    if (bot.ballRichtung() == -7) neueRichtung =  135;
    if (bot.ballRichtung() == -6) neueRichtung =  180;
    if (bot.ballRichtung() == -5) neueRichtung = -135;
    if (bot.ballRichtung() == -4) neueRichtung = -135;
    if (bot.ballRichtung() == -3) neueRichtung =  -90;
    if (bot.ballRichtung() == -2) neueRichtung =  -90;
    if (bot.ballRichtung() == -1) neueRichtung =  -45;

   bot.fahre(neueRichtung, tempo, bot.torRichtung() / 2);  
  if (alteRichtung != neueRichtung) bot.strikeZeit = 0;
    alteRichtung = neueRichtung;     
  
}
void play()
{
  if (bot.blindZeit < 2000)
  {
    bot.setLed(bot.rechtesModul, 1, WEISS);
    bot.setLed(bot.linkesModul,  2, AUS);
    if (!bot.siehtBall()) 
    {
      bot.setLed(bot.linkesModul, 2, ROT);
      bot.fahre(0, 0, bot.torRichtung() / 2);
    }
    else 
    {
      bot.setLed(bot.linkesModul, 2, AUS);
    
      if(bot.hatBall()) strike();
      else
      {
        bot.strikeZeit = 0;
        bot.setLed(bot.rechtesModul, 2, AUS);
        suche();
      }
    }

  }
  else 
  {
    //bot.fahre(0,0,30);
    bot.fahre(0, 0, altetorRichtung / 5);
  }
  if (bot.siehtTor()) 
  {
    bot.blindZeit = 0;
    altetorRichtung = bot.torRichtung();    
  }
}
/*
void play()
{
  bot.setLed(rechts,1,WEISS);
  bot.setLed(links,2,AUS);
  
  //bot.fahre(0,50,0);
  
  
}
*/
void loop()
{
  bot.warte(20); 
  
  
  if (bot.taster(bot.rechtesModul,1)) changeModus();
  if (modus == 0) vorbereitung();
  if (modus == 1) play();

}

void schreibe()
{ 
  Serial.println("+----------------+---------------------------------------");
  Serial.println("|  DEBUG START:  |                                       ");
  Serial.println("+----------------+                                       ");
  Serial.println("   [ Ball ]                                              ");
  Serial.println("        sieht:      " + String(bot.siehtBall()           ));
  Serial.println("        hat:        " + String(bot.hatBall()             ));
  Serial.println("        Richtung:   " + String(bot.ballRichtung()        ));
  Serial.println("        Entfernung: " + String(bot.ballEntfernung()      ));
  Serial.println("                                                         ");
  Serial.println("   [ Tor ]                                               ");
  Serial.println("        sieht:      " + String(bot.siehtTor()            ));
  Serial.println("        Richtung:   " + String(bot.torRichtung()         ));
  Serial.println("        Entfernung: " + String(bot.torEntfernung()       ));
  Serial.println("                                                         ");
  Serial.println("   [ Eigenes Tor ]                                       ");
  Serial.println("        sieht:      " + String(bot.siehtEigenesTor()     ));
  Serial.println("        Richtung:   " + String(bot.eigenesTorRichtung()  ));
  Serial.println("        Entfernung: " + String(bot.eigenesTorEntfernung()));
  Serial.println("                                                         ");
  Serial.println("   [ Lichtschranke ]                                     ");
  Serial.println("        Analogwert: " + String(bot.input(LICHT_PIN)      ));
  Serial.println("                                                         ");
  Serial.println("+---------------+                                        ");
  Serial.println("|  DEBUG ENDE:  |                                        ");
  Serial.println("+---------------+----------------------------------------");
}

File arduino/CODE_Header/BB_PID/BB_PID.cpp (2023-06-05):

// -------------------------------------------------------------------
//////////////////////////////////////////////////////////////////////
/**
*      BOHLEBOTS PID CONTROLLER CPP-FILE
*     
*      Version: 0.4.0
*      Date: 25. Mai 2023
*/
//////////////////////////////////////////////////////////////////////
// -------------------------------------------------------------------

#include "BB_PID.h"

////////////////////////////////////////////////////////////////
//--- CONSTRUCTOR --------------------------------------------//
////////////////////////////////////////////////////////////////

BB_PID::BB_PID() 
  : _setpoint(0.0),
    _Kp(0.0), _Ki(0.0), _Kd(0.0),
    _pTerm(0.0), _iTerm(0.0), _dTerm(0.0),
    _lastError(0.0),
    _minOutput(0.0), _maxOutput(1.0),
    _interval(1), _dt(0),
    _state(ON), _direction(DIRECT),
    _output(0.0), _transferFunctionPtr([](const double& d) { return d; }) {
}



////////////////////////////////////////////////////////////////
//--- SETTER FUNCTIONS ---------------------------------------//
////////////////////////////////////////////////////////////////

// setSetpoint
int BB_PID::setSetpoint(const double& setpoint) {
  // Execute
  this->_setpoint = setpoint;
  this->_iTerm = 0;
  return 0;
}

// setTunings
int BB_PID::setTunings(const double& kp, const double& ki, const double& kd) {
  // Check for Valid Input
  if (kp < 0 || ki < 0 || kd < 0) {
    return -1;
  }
  // Execute
  this->_Kp =   kp;
  this->_Ki =   ki / this->_interval;
  this->_Kd = - kd * this->_interval;
  if (this->_direction == REVERSE) {
    this->_Kp *= -1;
    this->_Ki *= -1;
    this->_Kd *= -1;
  }
  return 0;
}

// setInterval
int BB_PID::setInterval(const int& millis) {
  // Check for valid Input
  if (millis <= 0) {
    return -1;
  }
  // Execute
  double ratio = (double)millis / (double)this->_interval;
  this->_Ki /= ratio;
  this->_Kd *= ratio;
  this->_interval = millis;
  return 0;
}

// setOutputLimits
int BB_PID::setOutputLimits(const double& minOut, const double& maxOut) {
  // Check for valid Input
  if (minOut > maxOut) {
    return -1;
  }
  // Execute
  this->_minOutput = minOut;
  this->_maxOutput = maxOut;
  return 0;
}

// setState
int BB_PID::setState(const BB_PID_STATE& state) {
  // Execute
  this->_state = state;
  if (this->_state == OFF) {
    this->_iTerm = 0.0;
  }
  return 0;
}

// setDirection
int BB_PID::setDirection(const BB_PID_DIRECTION& direction) {
  // Execute
  if(this->_direction != direction) { 
    this->_direction = direction;
    this->_Kp *= -1;
    this->_Ki *= -1;
    this->_Kd *= -1;
  }
  return 0;
}

// setTransferFunction
int BB_PID::setTransferFunction(double (*functionPtr)(const double& d)) {
  // Execute
  this->_transferFunctionPtr = functionPtr;
  return 0;
}



////////////////////////////////////////////////////////////////
//--- COMPUTATION --------------------------------------------//
////////////////////////////////////////////////////////////////

// compute
int BB_PID::compute(const double& input) {
  // Check for valid Input
  if (this->_dt < this->_interval) {
    return -1;
  }
  if (this->_state == PAUSE) {
    return -2;
  }
  if (this->_state == OFF) {
    return -3;
  }
  // Execute
  double error = input - this->_setpoint;
  // Reset iTerm if error crosses 0
  if ((error > 0 && this->_lastError < 0) || (error < 0 && this->_lastError > 0)) {
    this->_iTerm = 0.0;
  }
  double dError = error - this->_lastError;
  this->_pTerm  = this->_Kp * error;
  this->_iTerm += this->_Ki * error * this->_interval;
  this->_dTerm  = this->_Kd * dError / this->_interval;
  this->_output = this->_pTerm + this->_iTerm - this->_dTerm;
  // Maybe needed corrections
  if (this->_output > this->_maxOutput) {
    this->_iTerm -= this->_output - this->_maxOutput;
    this->_output = this->_maxOutput;
  }
  if (this->_output < this->_minOutput) {
    this->_iTerm += this->_minOutput - this->_output;
    this->_output = this->_minOutput;
  }
  // Safe new values for next calculation
  this->_lastError  = error;
  this->_dt = 0;
  return 0;
}



////////////////////////////////////////////////////////////////
//--- GETTER FUNCTIONS ---------------------------------------//
////////////////////////////////////////////////////////////////

// getRawOutput
double BB_PID::getRawOutput() const {
  // Execute
  return this->_output;
}

// getTransferedOutput
double BB_PID::getTransferedOutput() const {
  // Execute
  return this->_transferFunctionPtr(this->_output);
}



////////////////////////////////////////////////////////////////
//--- DEBUG FUNCTIONS ---------------------------------------//
////////////////////////////////////////////////////////////////

// debugPrint
void BB_PID::debugPrint(const String& label) const {
  // String for verbal represenattion of the direction
  String sDirection = "undefined";
  switch(this->_direction) {
    case DIRECT:  sDirection = "DIRECT";  break;
    case REVERSE: sDirection = "REVERSE"; break;
  }
  // String for verbal represenattion of the state
  String sState     = "undefined";
  switch(this->_state) {
    case OFF:   sState = "OFF";   break;
    case PAUSE: sState = "PAUSE"; break;
    case ON:    sState = "ON";    break;
  }
  // Debug print
  Serial.println("+-----------------+--------------------------------------");
  Serial.println("| PID DEBUG START |" + label );
  Serial.println("+-----------------+");
  Serial.println("   [ Settings ]    ");
  Serial.println("        setpoint:  " + String(this->_setpoint ));
  Serial.println("        Kp:        " + String(this->_Kp       ));
  Serial.println("        Ki:        " + String(this->_Ki       ));
  Serial.println("        Kd:        " + String(this->_Kd       ));
  Serial.println("        minOutput: " + String(this->_minOutput));
  Serial.println("        maxOutput: " + String(this->_maxOutput));
  Serial.println("        interval:  " + String(this->_interval ));
  Serial.println("        direction: " + sDirection              );
  Serial.println("                   ");
  Serial.println("   [ State ]       ");
  Serial.println("        state:     " + sState                  );
  Serial.println("        pTerm:     " + String(this->_pTerm    ));
  Serial.println("        iTerm:     " + String(this->_iTerm    ));
  Serial.println("        dTerm:     " + String(this->_dTerm    ));
  Serial.println("        dt:        " + String(this->_dt       ));
  Serial.println("        lastError: " + String(this->_lastError));
  Serial.println("        output:    " + String(this->_output   ));
  Serial.println("                   ");
  Serial.println("+-----------------+");
  Serial.println("|  PID DEBUG END  |" + label );
  Serial.println("+-----------------+--------------------------------------");
}
